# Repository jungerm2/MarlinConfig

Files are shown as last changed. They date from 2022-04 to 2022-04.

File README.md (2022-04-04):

# MarlinConfig

This repo mainly serves as a backup of my Marlin config and notes to my future self to avoid any future headaches. My printer originally ran on Marlin 1.0, but I've since lost the configurations and upgraded it to Marlin 2.0. This repo contains the new configurations as of April 4th, 2022 such that I do not lose them again. 

In late 2015, I had made a Prusa i3 (rework) from scratch. I did not use any sort of kit, therefore I was limited in material usage. I could only laser cut wood so I tweaked the open-sourced parts to be more robust and rigid to compensate for the lack of an aluminum frame. This resulted in a wooden frame with perpendicular supports on either side. Below I detail some of the intricacies of this printer.

## Printer Setup

### Electronics

This custom printer uses an Arduino Mega with a RAMPS 1.4 (with A4988 stepper drivers). The electronics are all 12v, the motors are Nema 17s. I use two mechanical endstops, one for y_min, one for x_min, and an NPN type inductive probe (6-36v) as the z_min endstop. This also allows for automatic bed leveling. 

_**Important Note:**_ It seems that I have burnt out the E0 extruder slot on the RAMPS board. Because of this, my only extruder is wired on E1. To account for this I've changed the pins in `pins_RAMPS.h` and effectively flipped E1 with E0, see [here](https://3dprinting.stackexchange.com/questions/5840/how-to-change-e0-to-e1-on-marlin-1-1) for an (outdated) example of this.

### Mechanical

As mentioned above, the frame is laser cut wood. The Y-carriage is made of M10 threaded rods attached by printed parts. The threaded rods used to move the Z-axis are M5 rods. All smooth rods are M8s. All (yellow, and gold) printed parts are PLA. 

The hotend is a cheap E3D V6 clone with a Teflon-lined heat throat and 0.4 mm nozzle. The extruder is a geared wade's extruder (classic). The x-idler is custom and part files can be found above.

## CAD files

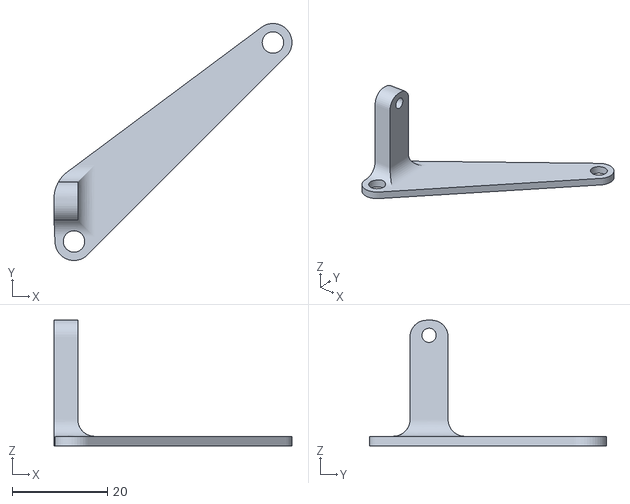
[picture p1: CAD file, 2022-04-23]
parts/FanMount-B.stl
49.9 x 49.7 x 26.3

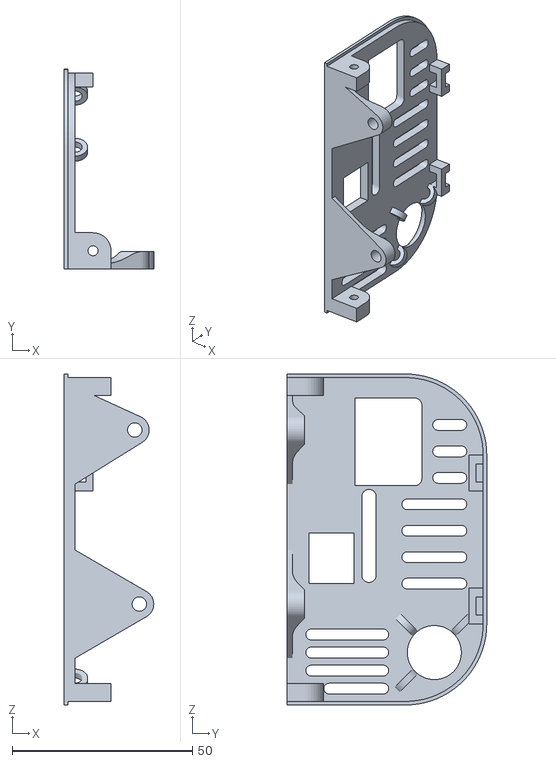
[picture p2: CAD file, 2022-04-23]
parts/RAMPS1.4 Case Front.stl
24.8 x 55.3 x 91.8

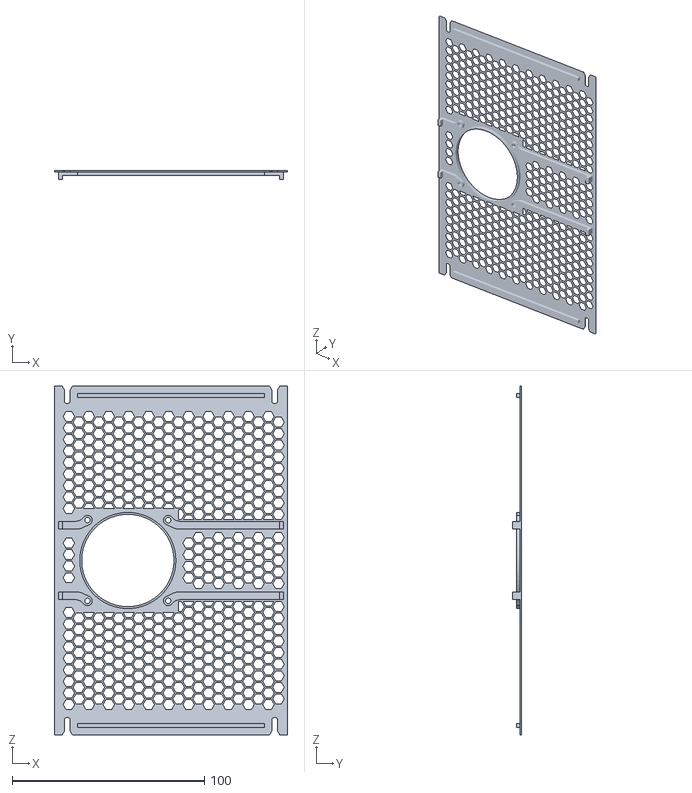
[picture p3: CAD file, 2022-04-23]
parts/RAMPS1.4 Case Cover.stl
121.5 x 4.70 x 181.6

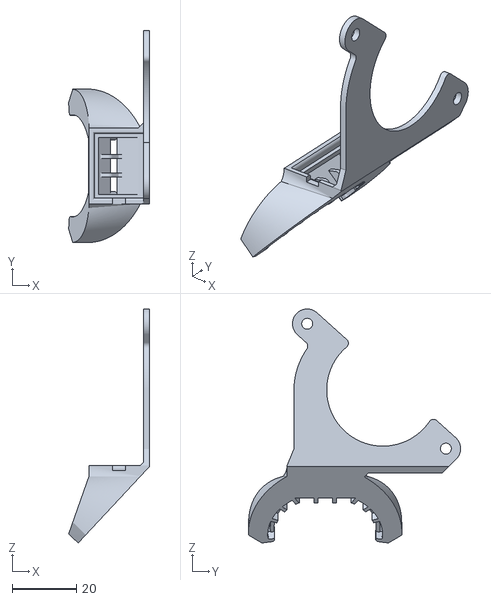
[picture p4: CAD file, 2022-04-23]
parts/SHROUD.stl
25.1 x 65.9 x 72.7

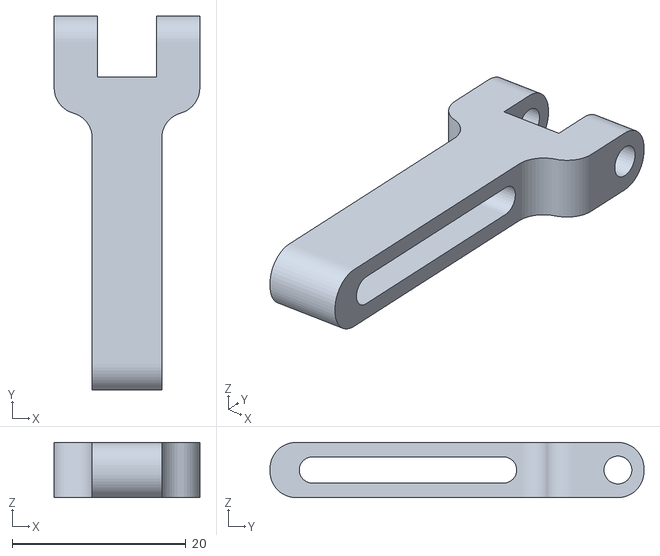
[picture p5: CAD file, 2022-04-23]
parts/FanMount-A.stl
16.8 x 43.0 x 6.35

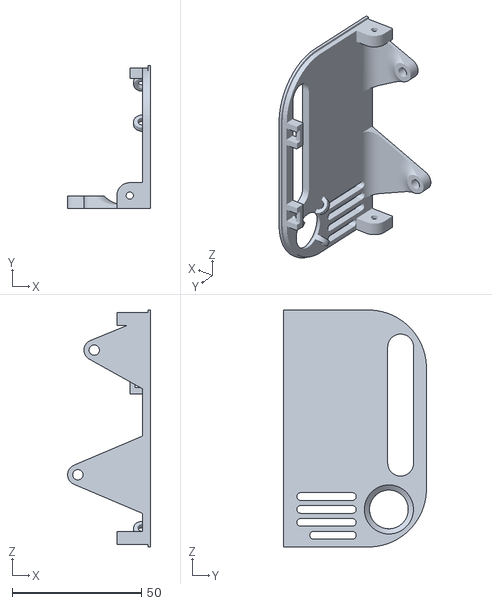
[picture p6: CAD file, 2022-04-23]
parts/RAMPS1.4 Case Back.stl
32.1 x 55.3 x 91.8

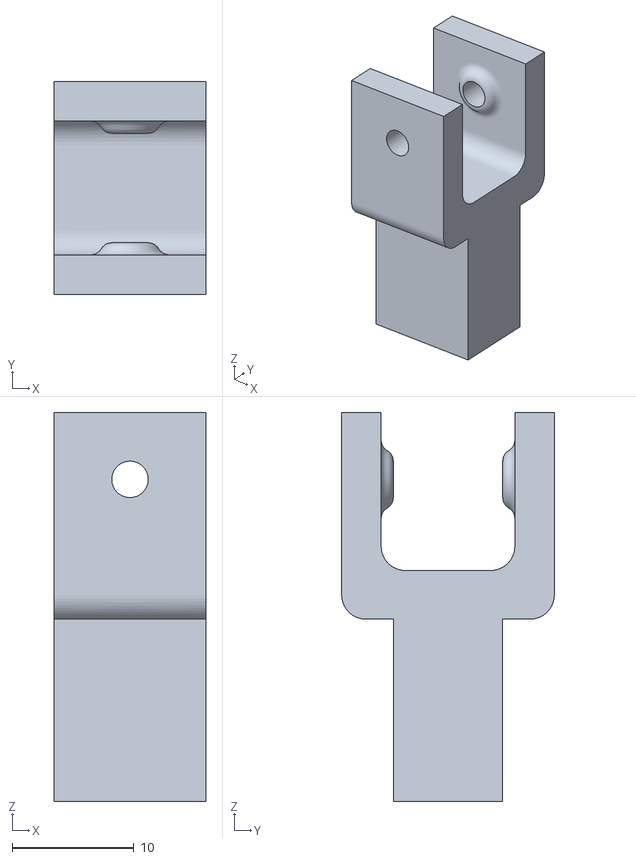
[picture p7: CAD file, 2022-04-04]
parts/x-idler.stl
12.5 x 17.5 x 32.0

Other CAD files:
parts/Fan Mount v1.f3d
parts/x-idler.f3d

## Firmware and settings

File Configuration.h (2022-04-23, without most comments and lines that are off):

#pragma once
#define CONFIGURATION_H_VERSION 02000903
#define STRING_CONFIG_H_AUTHOR "(Sacha Jungerman - 04/23/22, Prusa i3)" // Who made the changes.
  #define MOTHERBOARD BOARD_RAMPS_14_EFB
#define SERIAL_PORT 0
#define BAUDRATE 250000
#if LINEAR_AXES >= 4
  #define AXIS4_NAME 'A' // :['A', 'B', 'C', 'U', 'V', 'W']
#endif
#if LINEAR_AXES >= 5
  #define AXIS5_NAME 'B' // :['A', 'B', 'C', 'U', 'V', 'W']
#endif
#if LINEAR_AXES >= 6
  #define AXIS6_NAME 'C' // :['A', 'B', 'C', 'U', 'V', 'W']
#endif
#define EXTRUDERS 1
#define DEFAULT_NOMINAL_FILAMENT_DIA 1.75
#define TEMP_SENSOR_0 1
#define TEMP_SENSOR_1 0
#define TEMP_SENSOR_2 0
#define TEMP_SENSOR_3 0
#define TEMP_SENSOR_4 0
#define TEMP_SENSOR_5 0
#define TEMP_SENSOR_6 0
#define TEMP_SENSOR_7 0
#define TEMP_SENSOR_BED 1
#define TEMP_SENSOR_PROBE 0
#define TEMP_SENSOR_CHAMBER 0
#define TEMP_SENSOR_COOLER 0
#define TEMP_SENSOR_BOARD 0
#define TEMP_SENSOR_REDUNDANT 0
#define DUMMY_THERMISTOR_998_VALUE  25
#define DUMMY_THERMISTOR_999_VALUE 100
#define TEMP_RESIDENCY_TIME         10  // (seconds) Time to wait for hotend to "settle" in M109
#define TEMP_WINDOW                  1  // (°C) Temperature proximity for the "temperature reached" timer
#define TEMP_HYSTERESIS              3  // (°C) Temperature proximity considered "close enough" to the target
#define TEMP_BED_RESIDENCY_TIME     10  // (seconds) Time to wait for bed to "settle" in M190
#define TEMP_BED_WINDOW              1  // (°C) Temperature proximity for the "temperature reached" timer
#define TEMP_BED_HYSTERESIS          3  // (°C) Temperature proximity considered "close enough" to the target
#define TEMP_CHAMBER_RESIDENCY_TIME 10  // (seconds) Time to wait for chamber to "settle" in M191
#define TEMP_CHAMBER_WINDOW          1  // (°C) Temperature proximity for the "temperature reached" timer
#define TEMP_CHAMBER_HYSTERESIS      3  // (°C) Temperature proximity considered "close enough" to the target
#if TEMP_SENSOR_REDUNDANT
  #define TEMP_SENSOR_REDUNDANT_SOURCE    E1  // The sensor that will provide the redundant reading.
  #define TEMP_SENSOR_REDUNDANT_TARGET    E0  // The sensor that we are providing a redundant reading for.
  #define TEMP_SENSOR_REDUNDANT_MAX_DIFF  10  // (°C) Temperature difference that will trigger a print abort.
#endif
#define HEATER_0_MINTEMP   5
#define HEATER_1_MINTEMP   5
#define HEATER_2_MINTEMP   5
#define HEATER_3_MINTEMP   5
#define HEATER_4_MINTEMP   5
#define HEATER_5_MINTEMP   5
#define HEATER_6_MINTEMP   5
#define HEATER_7_MINTEMP   5
#define BED_MINTEMP        5
#define CHAMBER_MINTEMP    5
#define HEATER_0_MAXTEMP 275
#define HEATER_1_MAXTEMP 275
#define HEATER_2_MAXTEMP 275
#define HEATER_3_MAXTEMP 275
#define HEATER_4_MAXTEMP 275
#define HEATER_5_MAXTEMP 275
#define HEATER_6_MAXTEMP 275
#define HEATER_7_MAXTEMP 275
#define BED_MAXTEMP      150
#define CHAMBER_MAXTEMP  60
#define HOTEND_OVERSHOOT 15   // (°C) Forbid temperatures over MAXTEMP - OVERSHOOT
#define BED_OVERSHOOT    10   // (°C) Forbid temperatures over MAXTEMP - OVERSHOOT
#define COOLER_OVERSHOOT  2   // (°C) Forbid temperatures closer than OVERSHOOT
#define PIDTEMP
#define BANG_MAX 255     // Limits current to nozzle while in bang-bang mode; 255=full current
#define PID_MAX BANG_MAX // Limits current to nozzle while PID is active (see PID_FUNCTIONAL_RANGE below); 255=full current
#define PID_K1 0.95      // Smoothing factor within any PID loop
    #define DEFAULT_Kp 45.48
    #define DEFAULT_Ki 4.70
    #define DEFAULT_Kd 109.91
#define PIDTEMPBED
#define MAX_BED_POWER 255 // limits duty cycle to bed; 255=full current
  #define DEFAULT_bedKp 46.27
  #define DEFAULT_bedKi 5.54
  #define DEFAULT_bedKd 257.74
#define MAX_CHAMBER_POWER 255 // limits duty cycle to chamber heater; 255=full current
  #define PID_FUNCTIONAL_RANGE 10 // If the temperature difference between the target temperature and the actual temperature
#define PREVENT_COLD_EXTRUSION
#define EXTRUDE_MINTEMP 170
#define PREVENT_LENGTHY_EXTRUDE
#define EXTRUDE_MAXLENGTH 200
#define THERMAL_PROTECTION_HOTENDS // Enable thermal protection for all extruders
#define THERMAL_PROTECTION_BED     // Enable thermal protection for the heated bed
#define THERMAL_PROTECTION_CHAMBER // Enable thermal protection for the heated chamber
#define THERMAL_PROTECTION_COOLER  // Enable thermal protection for the laser cooling
#define USE_XMIN_PLUG
#define USE_YMIN_PLUG
#define USE_ZMIN_PLUG
#define ENDSTOPPULLUPS
#define X_MIN_ENDSTOP_INVERTING true  // Set to true to invert the logic of the endstop.    // TODO!
#define Y_MIN_ENDSTOP_INVERTING false // Set to true to invert the logic of the endstop.
#define Z_MIN_ENDSTOP_INVERTING true  // Set to true to invert the logic of the endstop.
#define I_MIN_ENDSTOP_INVERTING false // Set to true to invert the logic of the endstop.
#define J_MIN_ENDSTOP_INVERTING false // Set to true to invert the logic of the endstop.
#define K_MIN_ENDSTOP_INVERTING false // Set to true to invert the logic of the endstop.
#define X_MAX_ENDSTOP_INVERTING false // Set to true to invert the logic of the endstop.
#define Y_MAX_ENDSTOP_INVERTING false // Set to true to invert the logic of the endstop.
#define Z_MAX_ENDSTOP_INVERTING false // Set to true to invert the logic of the endstop.
#define I_MAX_ENDSTOP_INVERTING false // Set to true to invert the logic of the endstop.
#define J_MAX_ENDSTOP_INVERTING false // Set to true to invert the logic of the endstop.
#define K_MAX_ENDSTOP_INVERTING false // Set to true to invert the logic of the endstop.
#define Z_MIN_PROBE_ENDSTOP_INVERTING true // Set to true to invert the logic of the probe.
#define X_DRIVER_TYPE  A4988
#define Y_DRIVER_TYPE  A4988
#define Z_DRIVER_TYPE  A4988
#define E0_DRIVER_TYPE A4988
#define ENDSTOP_NOISE_THRESHOLD 2
#define DEFAULT_AXIS_STEPS_PER_UNIT   { 80, 80, 4000, 732 }
#define DEFAULT_MAX_FEEDRATE          { 250, 250, 3.3, 25 }
#define DEFAULT_MAX_ACCELERATION      { 3000, 3000, 100, 10000 }
#define DEFAULT_ACCELERATION          1000    // X, Y, Z and E acceleration for printing moves
#define DEFAULT_RETRACT_ACCELERATION  1000    // E acceleration for retracts
#define DEFAULT_TRAVEL_ACCELERATION   1000    // X, Y, Z acceleration for travel (non printing) moves
#define DEFAULT_EJERK    5.0  // May be used by Linear Advance
  #define JUNCTION_DEVIATION_MM 0.013 // (mm) Distance from real junction edge
  #define JD_HANDLE_SMALL_SEGMENTS    // Use curvature estimation instead of just the junction angle
#define Z_MIN_PROBE_USES_Z_MIN_ENDSTOP_PIN
#define FIX_MOUNTED_PROBE
#define NOZZLE_TO_PROBE_OFFSET_X 31
#define NOZZLE_TO_PROBE_OFFSET_Y 18
#define NOZZLE_TO_PROBE_OFFSET_Z -1.3   // TODO: Z-OFFSET HERE! (Negative because probe too high)
#define NOZZLE_TO_PROBE_OFFSET {NOZZLE_TO_PROBE_OFFSET_X, NOZZLE_TO_PROBE_OFFSET_Y, NOZZLE_TO_PROBE_OFFSET_Z}
#define PROBING_MARGIN 35
#define XY_PROBE_FEEDRATE (133*60)
#define Z_PROBE_FEEDRATE_FAST (4*60)
#define Z_PROBE_FEEDRATE_SLOW (Z_PROBE_FEEDRATE_FAST / 2)
#define MULTIPLE_PROBING 2
#define Z_CLEARANCE_DEPLOY_PROBE    0 // Z Clearance for Deploy/Stow
#define Z_CLEARANCE_BETWEEN_PROBES  5 // Z Clearance between probe points
#define Z_CLEARANCE_MULTI_PROBE     5 // Z Clearance between multiple probes
#define Z_PROBE_LOW_POINT          -2 // Farthest distance below the trigger-point to go before stopping
#define Z_PROBE_OFFSET_RANGE_MIN -20
#define Z_PROBE_OFFSET_RANGE_MAX 20
#define Z_MIN_PROBE_REPEATABILITY_TEST
#define X_ENABLE_ON 0
#define Y_ENABLE_ON 0
#define Z_ENABLE_ON 0
#define E_ENABLE_ON 0 // For all extruders
#define DISABLE_X false
#define DISABLE_Y false
#define DISABLE_Z false
#define DISABLE_E false             // Disable the extruder when not stepping
#define DISABLE_INACTIVE_EXTRUDER   // Keep only the active extruder enabled
#define INVERT_X_DIR true  // TODO: Fix these and endstops!
#define INVERT_Y_DIR true
#define INVERT_Z_DIR true
#define INVERT_E0_DIR true
#define INVERT_E1_DIR false
#define INVERT_E2_DIR false
#define INVERT_E3_DIR false
#define INVERT_E4_DIR false
#define INVERT_E5_DIR false
#define INVERT_E6_DIR false
#define INVERT_E7_DIR false
#define NO_MOTION_BEFORE_HOMING // Inhibit movement until all axes have been homed. Also enable HOME_AFTER_DEACTIVATE for extra safety.
#define X_HOME_DIR -1  // TODO: Fix this too
#define Y_HOME_DIR -1
#define Z_HOME_DIR -1
#define X_BED_SIZE 208
#define Y_BED_SIZE 200
#define X_MIN_POS -16
#define Y_MIN_POS 0
#define Z_MIN_POS 0
#define X_MAX_POS X_BED_SIZE + 3
#define Y_MAX_POS Y_BED_SIZE
#define Z_MAX_POS 190
#define MIN_SOFTWARE_ENDSTOPS
  #define MIN_SOFTWARE_ENDSTOP_X
  #define MIN_SOFTWARE_ENDSTOP_Y
  #define MIN_SOFTWARE_ENDSTOP_Z
  #define MIN_SOFTWARE_ENDSTOP_I
  #define MIN_SOFTWARE_ENDSTOP_J
  #define MIN_SOFTWARE_ENDSTOP_K
#define MAX_SOFTWARE_ENDSTOPS
  #define MAX_SOFTWARE_ENDSTOP_X
  #define MAX_SOFTWARE_ENDSTOP_Y
  #define MAX_SOFTWARE_ENDSTOP_Z
  #define MAX_SOFTWARE_ENDSTOP_I
  #define MAX_SOFTWARE_ENDSTOP_J
  #define MAX_SOFTWARE_ENDSTOP_K
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

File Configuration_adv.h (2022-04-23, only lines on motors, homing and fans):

#define E0_AUTO_FAN_PIN -1
#define E1_AUTO_FAN_PIN -1
#define E2_AUTO_FAN_PIN -1
#define E3_AUTO_FAN_PIN -1
#define E4_AUTO_FAN_PIN -1
#define E5_AUTO_FAN_PIN -1
#define E6_AUTO_FAN_PIN -1
#define E7_AUTO_FAN_PIN -1
#define CHAMBER_AUTO_FAN_PIN -1
#define COOLER_AUTO_FAN_PIN -1
#define COOLER_FAN_PIN -1
#define HOMING_BUMP_MM      { 5, 5, 2 }       // (mm) Backoff from endstops after first bump
#define HOMING_BUMP_DIVISOR { 2, 2, 4 }       // Re-Bump Speed Divisor (Divides the Homing Feedrate)
#define MICROSTEP_MODES { 16, 16, 16, 16, 16, 16 } // [1,2,4,8,16]
#define LIN_ADVANCE
  #define LIN_ADVANCE_K 0.06    // Unit: mm compression per 1mm/s extruder speed
#define ADVANCED_PAUSE_FEATURE
  #define ADVANCED_PAUSE_PURGE_FEEDRATE        3  // (mm/s) Extrude feedrate (after loading). Should be slower than load feedrate.
  #define ADVANCED_PAUSE_PURGE_LENGTH         50  // (mm) Length to extrude after loading.
  #define ADVANCED_PAUSE_RESUME_PRIME          0  // (mm) Extra distance to prime nozzle after returning from park.

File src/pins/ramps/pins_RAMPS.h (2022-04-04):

/**
 * Marlin 3D Printer Firmware
 * Copyright (c) 2020 MarlinFirmware [https://github.com/MarlinFirmware/Marlin]
 *
 * Based on Sprinter and grbl.
 * Copyright (c) 2011 Camiel Gubbels / Erik van der Zalm
 *
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
 */
#pragma once

/**
 * Arduino Mega with RAMPS v1.4 (or v1.3) pin assignments
 *
 * Applies to the following boards:
 *
 *  RAMPS_14_EFB (Hotend, Fan, Bed)
 *  RAMPS_14_EEB (Hotend0, Hotend1, Bed)
 *  RAMPS_14_EFF (Hotend, Fan0, Fan1)
 *  RAMPS_14_EEF (Hotend0, Hotend1, Fan)
 *  RAMPS_14_SF  (Spindle, Controller Fan)
 *
 *  RAMPS_13_EFB (Hotend, Fan, Bed)
 *  RAMPS_13_EEB (Hotend0, Hotend1, Bed)
 *  RAMPS_13_EFF (Hotend, Fan0, Fan1)
 *  RAMPS_13_EEF (Hotend0, Hotend1, Fan)
 *  RAMPS_13_SF  (Spindle, Controller Fan)
 *
 *  Other pins_MYBOARD.h files may override these defaults
 *
 *  Differences between
 *  RAMPS_13 | RAMPS_14
 *         7 | 11
 */

#if ENABLED(AZSMZ_12864) && DISABLED(ALLOW_SAM3X8E)
  #error "No pins defined for RAMPS with AZSMZ_12864."
#endif

#include "env_validate.h"

// Custom flags and defines for the build
//#define BOARD_CUSTOM_BUILD_FLAGS -D__FOO__

#ifndef BOARD_INFO_NAME
  #define BOARD_INFO_NAME "RAMPS 1.4"
#endif

//
// Servos
//
#ifndef SERVO0_PIN
  #ifdef IS_RAMPS_13
    #define SERVO0_PIN                         7
  #else
    #define SERVO0_PIN                        11
  #endif
#endif
#ifndef SERVO1_PIN
  #define SERVO1_PIN                           6
#endif
#ifndef SERVO2_PIN
  #define SERVO2_PIN                           5
#endif
#ifndef SERVO3_PIN
  #define SERVO3_PIN                           4
#endif

//
// Limit Switches
//
#ifndef X_STOP_PIN
  #ifndef X_MIN_PIN
    #define X_MIN_PIN                          3
  #endif
  #ifndef X_MAX_PIN
    #define X_MAX_PIN                          2
  #endif
#endif
#ifndef Y_STOP_PIN
  #ifndef Y_MIN_PIN
    #define Y_MIN_PIN                         14
  #endif
  #ifndef Y_MAX_PIN
    #define Y_MAX_PIN                         15
  #endif
#endif
#ifndef Z_STOP_PIN
  #ifndef Z_MIN_PIN
    #define Z_MIN_PIN                         18
  #endif
  #ifndef Z_MAX_PIN
    #define Z_MAX_PIN                         19
  #endif
#endif

//
// Z Probe (when not Z_MIN_PIN)
//
#ifndef Z_MIN_PROBE_PIN
  #define Z_MIN_PROBE_PIN                     32
#endif

//
// Steppers
//
#define X_STEP_PIN                            54
#define X_DIR_PIN                             55
#define X_ENABLE_PIN                          38
#ifndef X_CS_PIN
  #define X_CS_PIN                   AUX3_03_PIN
#endif

#define Y_STEP_PIN                            60
#define Y_DIR_PIN                             61
#define Y_ENABLE_PIN                          56
#ifndef Y_CS_PIN
  #define Y_CS_PIN                   AUX3_07_PIN
#endif

#ifndef Z_STEP_PIN
  #define Z_STEP_PIN                          46
#endif
#ifndef Z_DIR_PIN
  #define Z_DIR_PIN                           48
#endif
#ifndef Z_ENABLE_PIN
  #define Z_ENABLE_PIN                        62
#endif
#ifndef Z_CS_PIN
  #define Z_CS_PIN                            40
#endif

#ifndef E1_STEP_PIN
  #define E1_STEP_PIN                         26
#endif
#ifndef E1_DIR_PIN
  #define E1_DIR_PIN                          28
#endif
#ifndef E1_ENABLE_PIN
  #define E1_ENABLE_PIN                       24
#endif
#ifndef E1_CS_PIN
  #define E1_CS_PIN                           42
#endif

#ifndef E0_STEP_PIN
  #define E0_STEP_PIN                         36
#endif
#ifndef E0_DIR_PIN
  #define E0_DIR_PIN                          34
#endif
#ifndef E0_ENABLE_PIN
  #define E0_ENABLE_PIN                       30
#endif
#ifndef E0_CS_PIN
  #define E0_CS_PIN                           44
#endif

//
// Temperature Sensors
//
#ifndef TEMP_0_PIN
  #define TEMP_0_PIN                          13  // Analog Input
#endif
#ifndef TEMP_1_PIN
  #define TEMP_1_PIN                          15  // Analog Input
#endif
#ifndef TEMP_BED_PIN
  #define TEMP_BED_PIN                        14  // Analog Input
#endif

//
// SPI for MAX Thermocouple
//
#ifndef TEMP_0_CS_PIN
  #define TEMP_0_CS_PIN                       66  // Don't use 53 if using Display/SD card (SDSS) or 49 (SD_DETECT_PIN)
#endif

//
// Heaters / Fans
//
#ifndef MOSFET_A_PIN
  #define MOSFET_A_PIN                        10
#endif
#ifndef MOSFET_B_PIN
  #define MOSFET_B_PIN                         9
#endif
#ifndef MOSFET_C_PIN
  #define MOSFET_C_PIN                         8
#endif
#ifndef MOSFET_D_PIN
  #define MOSFET_D_PIN                        -1
#endif

#define HEATER_0_PIN                MOSFET_A_PIN
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

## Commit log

2020-05-12 it works
    [Configuration.h, Configuration_adv.h]
2022-04-04 update to 02000903, add lin-advance, eeprom, park head
    [Configuration-02000903.h, Configuration_adv-02000903.h, x-idler.f3d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]
2022-04-04 make x-idler thinner
    [x-idler.f3d, x-idler.stl]
2022-04-23 PID/Z-offset calibration + Case/Fan Mount
    [Configuration-02000903.h, Configuration.h, Configuration_adv-02000903.h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]

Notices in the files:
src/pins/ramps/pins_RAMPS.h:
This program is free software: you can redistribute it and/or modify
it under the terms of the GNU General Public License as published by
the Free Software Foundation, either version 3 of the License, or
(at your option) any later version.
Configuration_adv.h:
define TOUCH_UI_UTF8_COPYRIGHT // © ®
